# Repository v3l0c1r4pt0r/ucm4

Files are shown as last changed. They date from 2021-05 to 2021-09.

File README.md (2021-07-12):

# uCM4

Raspberry Pi Compute Module 4 micro carrier board

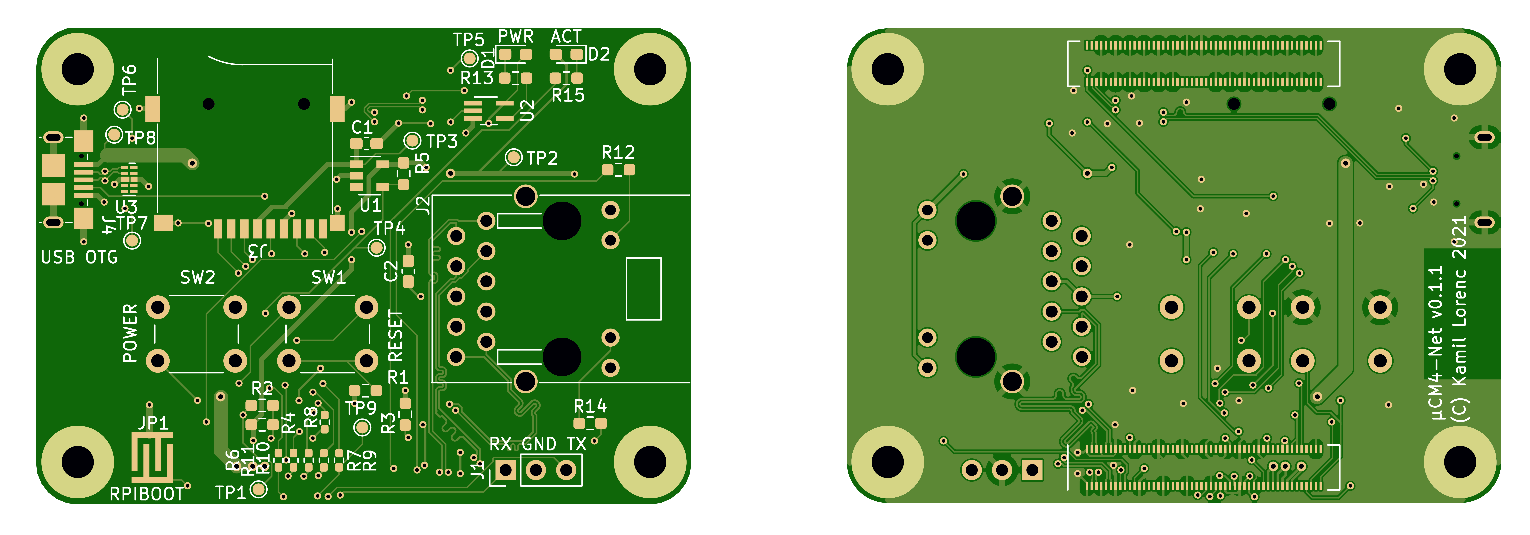
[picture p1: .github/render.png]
PCB render


# Features

* exactly same size as CM4
* support for both Lite and eMMC variants of CM4
* Gigabit Ethernet
* microSD slot (optional)
* Micro USB for power and USB 2.0 data transfer
* USB-OTG support

# Table of contents

1. [Customizations](customizations.md)
2. [Troubleshooting](troubleshooting.md)

# Project page

Complete project page with pictures, updates and so on, is available at
[Hackaday.io](https://hackaday.io/project/179793-ucm4).

# License

This work is licensed under a [Creative Commons Attribution 4.0 International License][cc-by].

You can use it for anything as long as you preserve license file and author information in source distribution and authorship information on PCB. Derived work should mention original author in same locations as this repository.

[][cc-by]

[cc-by]: http://creativecommons.org/licenses/by/4.0/
[cc-by-image]: https://i.creativecommons.org/l/by/4.0/88x31.png

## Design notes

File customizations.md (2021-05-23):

# uCM4 customizations

Following items can be changed without redesigning the board

## No microSD slot

microSD slot has been designed to be optional feature. For this purpose 0 Ohm
resistors are placed on data lines as close to Hirose connector, as was
possible. Following items should not be fitted in this case:

1. TF-015 microSD slot
2. R6-R11 0 Ohm resistors
3. RT9742CGJ5F chip marked as U1
4. R5 resistor between `SD_PWR_ON` and `SD_EN`

## Writable EEPROM

By default CM4 EEPROM has been locked, meaning it cannot be written to. This
lock can be lifted by removing R3 0 Ohm resistor.

## Power and reset buttons

These buttons can be either fitted, or not, depending on user preference.

## UART header

Same as with buttons. Can be skipped, depending on preference.

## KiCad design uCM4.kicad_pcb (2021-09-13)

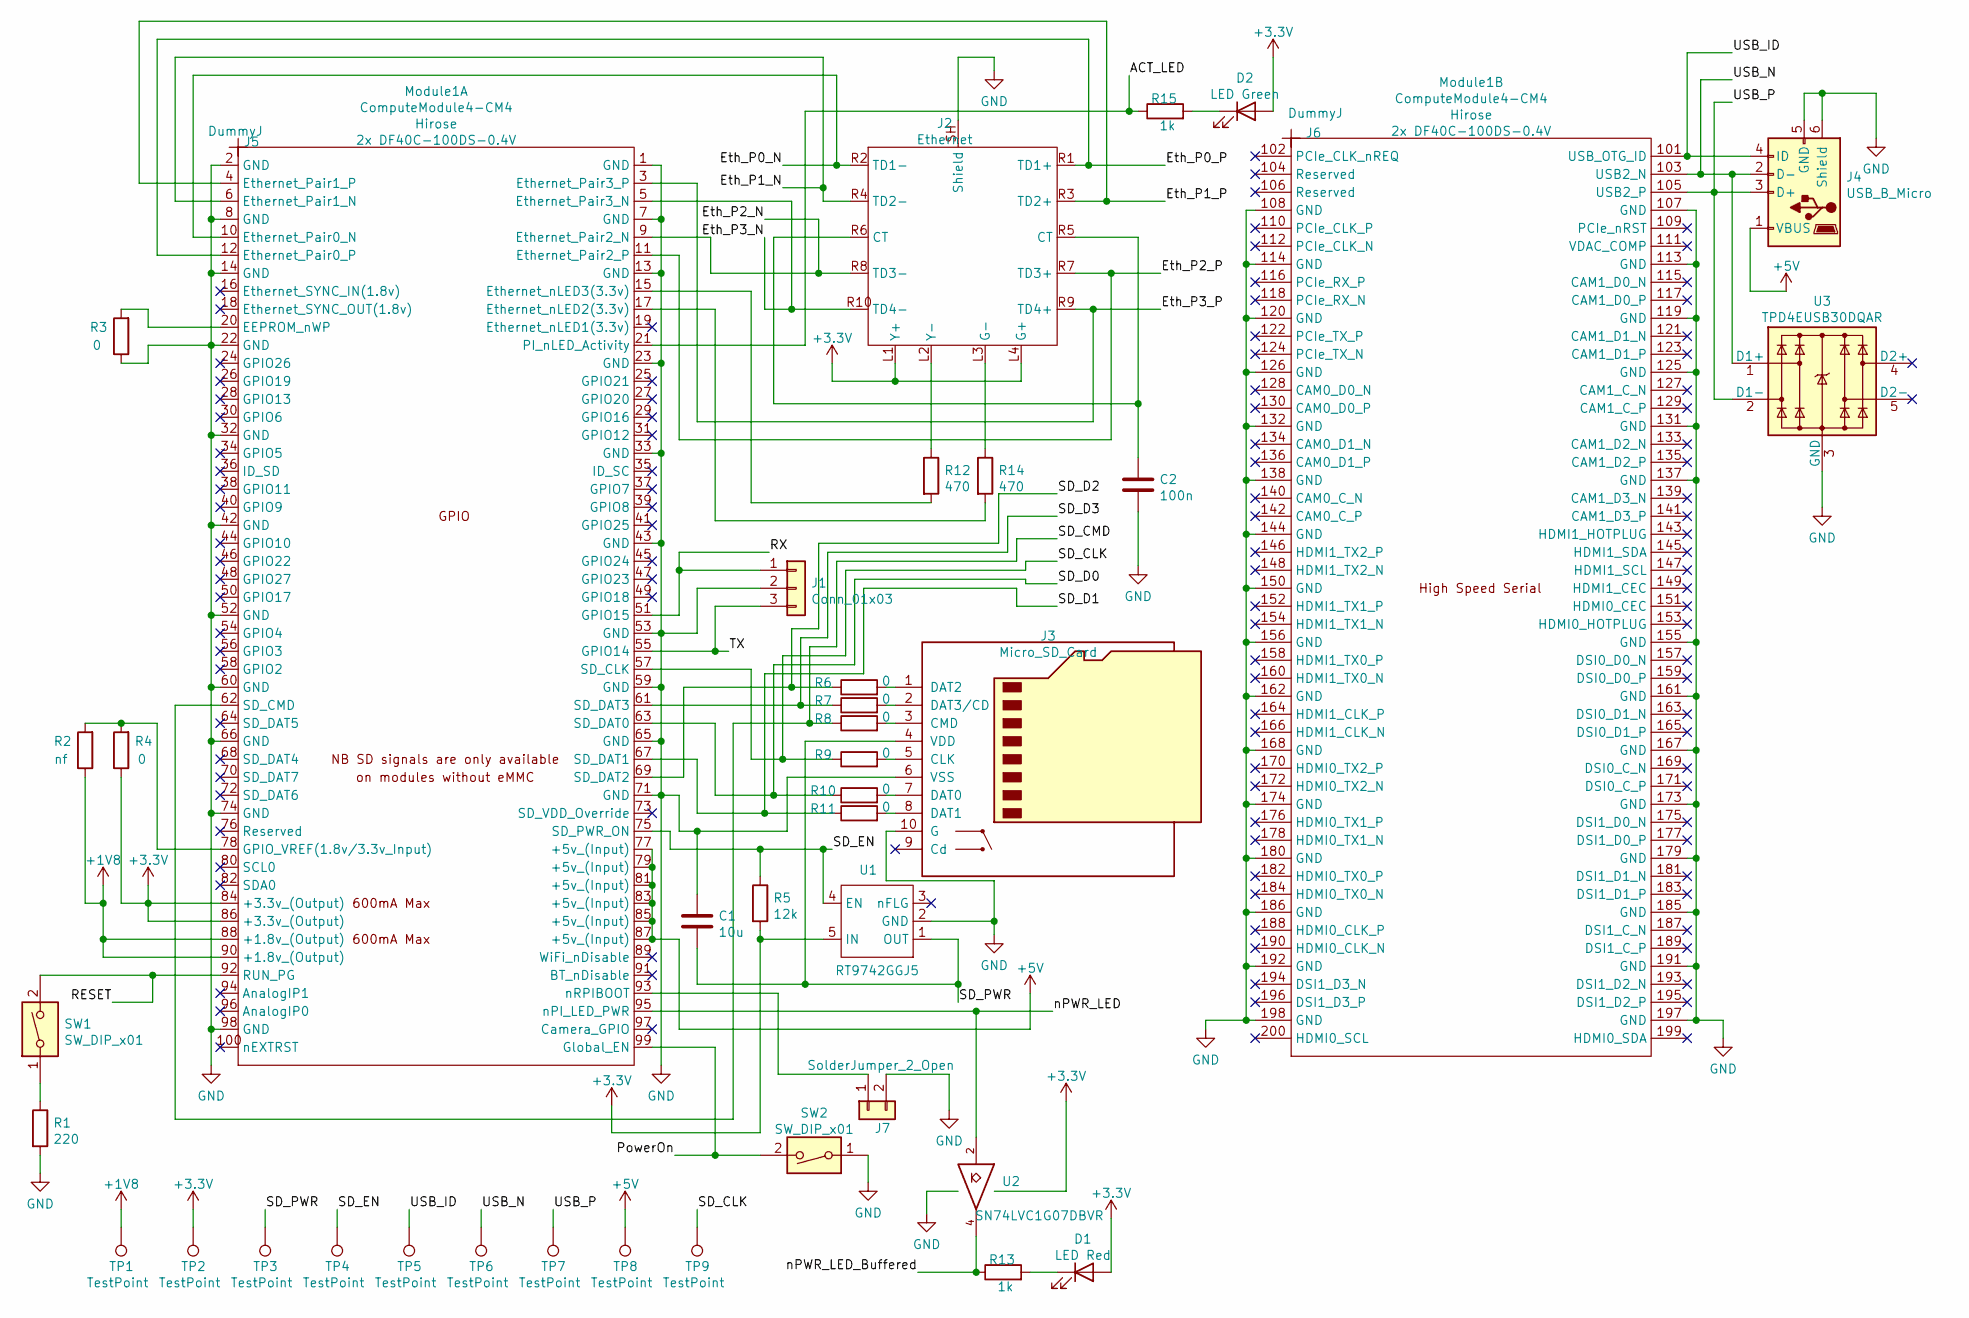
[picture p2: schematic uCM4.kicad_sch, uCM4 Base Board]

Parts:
C1: 10u; C_0603_1608Metric_Pad1.08x0.95mm_HandSolder; LCSC# C326057
C2: 100n; C_0603_1608Metric_Pad1.08x0.95mm_HandSolder; LCSC# C108079
D1: LED Red; LED_0603_1608Metric_Pad1.05x0.95mm_HandSolder; LCSC# C181863
D2: LED Green; LED_0603_1608Metric_Pad1.05x0.95mm_HandSolder; LCSC# C72043
J1: Conn_01x03; PinHeader_1x03_P2.54mm_Vertical; LCSC# C49257
J2: Ethernet; RB1-2S5BAK1A; LCSC# C363232
J3: Micro_SD_Card; TF-015; LCSC# C113206
J4: USB_B_Micro; U254-05XX-4BH81; LCSC# C2682232
J5, J6: DummyJ; LCSC# C424649
J7: SolderJumper_2_Open; PinHeader_1x02_P2.54mm_Vertical
Module1: ComputeModule4-CM4; Raspberry-Pi-4-Compute-Module; LCSC# C424649
R1: 220; R_0603_1608Metric_Pad0.98x0.95mm_HandSolder; LCSC# C22962
R2: nf; R_0603_1608Metric_Pad0.98x0.95mm_HandSolder
R3, R4: 0; R_0603_1608Metric_Pad0.98x0.95mm_HandSolder; LCSC# C21189
R5: 12k; R_0603_1608Metric_Pad0.98x0.95mm_HandSolder; LCSC# C22790
R6, R7, R8, R9, R10, R11: 0; R_0402_1005Metric_Pad0.72x0.64mm_HandSolder; LCSC# C17168
R12, R14: 470; R_0603_1608Metric_Pad0.98x0.95mm_HandSolder; LCSC# C23179
R13, R15: 1k; R_0603_1608Metric_Pad0.98x0.95mm_HandSolder; LCSC# C21190
SW1, SW2: SW_DIP_x01; PTS840_PM_SMTR_LFS; LCSC# C221911
TP1, TP2, TP3, TP4, TP5, TP6, TP7, TP8, TP9: TestPoint; TestPoint_Pad_D1.0mm
U1: RT9742GGJ5; SOT-23-5; Part Description Power Switch/Driver 1:1 N-Channel 1A TS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; LCSC# C2693603
U2: SN74LVC1G07DBVR; SOT-23-5_HandSoldering; LCSC# C7829
U3: TPD4EUSB30DQAR; USON-10_2.5x1.0mm_P0.5mm; LCSC# C90627

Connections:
+1V8: Module1.88 (+1.8v_(Output)), Module1.90 (+1.8v_(Output)), R2.1, TP1.1
+3V3: D1.2 (A), D2.2 (A), J2.L1 (Y+), J2.L4 (G+), Module1.84 (+3.3v_(Output)), Module1.86 (+3.3v_(Output)), R4.1, R5.2, TP2.1, U1.5 (IN), U2.5 (VCC)
+5V: J4.1 (VBUS), Module1.77 (+5v_(Input)), Module1.79 (+5v_(Input)), Module1.81 (+5v_(Input)), Module1.83 (+5v_(Input)), Module1.85 (+5v_(Input)), Module1.87 (+5v_(Input)), TP8.1
/ACT_LED: Module1.21 (PI_nLED_Activity), R15.1
/Eth_P0_N: J2.R2 (TD1-), Module1.10 (Ethernet_Pair0_N)
/Eth_P0_P: J2.R1 (TD1+), Module1.12 (Ethernet_Pair0_P)
/Eth_P1_N: J2.R4 (TD2-), Module1.6 (Ethernet_Pair1_N)
/Eth_P1_P: J2.R3 (TD2+), Module1.4 (Ethernet_Pair1_P)
/Eth_P2_N: J2.R8 (TD3-), Module1.9 (Ethernet_Pair2_N)
/Eth_P2_P: J2.R7 (TD3+), Module1.11 (Ethernet_Pair2_P)
/Eth_P3_N: J2.R10 (TD4-), Module1.5 (Ethernet_Pair3_N)
/Eth_P3_P: J2.R9 (TD4+), Module1.3 (Ethernet_Pair3_P)
/PowerOn: Module1.99 (Global_EN), SW2.2
/RESET: Module1.92 (RUN_PG), SW1.2
/RX: J1.1, Module1.51 (GPIO15)
/SD_CLK: Module1.57 (SD_CLK), R9.1, TP9.1
/SD_CMD: Module1.62 (SD_CMD), R8.1
/SD_D0: Module1.63 (SD_DAT0), R10.1
/SD_D1: Module1.67 (SD_DAT1), R11.1
/SD_D2: Module1.69 (SD_DAT2), R6.1
/SD_D3: Module1.61 (SD_DAT3), R7.1
/SD_EN: Module1.75 (SD_PWR_ON), R5.1, TP4.1, U1.4 (EN)
/SD_PWR: C1.2, J3.4 (VDD), TP3.1, U1.1 (OUT)
/TX: J1.3, Module1.55 (GPIO14)
/USB_ID: J4.4 (ID), Module1.101 (USB_OTG_ID), TP5.1
/USB_N: J4.2 (D-), Module1.103 (USB2_N), TP6.1, U3.1 (D1+)
/USB_P: J4.3 (D+), Module1.105 (USB2_P), TP7.1, U3.2 (D1-)
/nPWR_LED: Module1.95 (nPI_LED_PWR), U2.2
/nPWR_LED_Buffered: R13.1, U2.4
GND: C1.1, C2.2, J1.2, J2.SH (Shield), J3.6 (VSS), J3.10 (G), J4.5 (GND), J4.6 (Shield), J7.2, Module1.1 (GND), Module1.2 (GND), Module1.7 (GND), Module1.8 (GND), Module1.13 (GND), Module1.14 (GND), Module1.22 (GND), Module1.23 (GND), Module1.32 (GND), Module1.33 (GND), Module1.42 (GND), Module1.43 (GND), Module1.52 (GND), Module1.53 (GND), Module1.59 (GND), Module1.60 (GND), Module1.65 (GND), Module1.66 (GND), Module1.71 (GND), Module1.74 (GND), Module1.98 (GND), Module1.107 (GND), Module1.108 (GND), Module1.113 (GND), Module1.114 (GND), Module1.119 (GND), Module1.120 (GND), Module1.125 (GND), Module1.126 (GND), Module1.131 (GND), Module1.132 (GND), Module1.137 (GND), Module1.138 (GND), Module1.144 (GND), Module1.150 (GND), Module1.155 (GND), Module1.156 (GND), Module1.161 (GND), Module1.162 (GND), Module1.167 (GND), Module1.168 (GND), Module1.173 (GND), Module1.174 (GND), Module1.179 (GND), Module1.180 (GND), Module1.185 (GND), Module1.186 (GND), Module1.191 (GND), Module1.192 (GND), Module1.197 (GND), Module1.198 (GND), R1.2, R3.1, SW2.1, U1.2 (GND), U2.3 (GND), U3.3 (GND), U3.8 (GND)
unnamed: C2.1, J2.R5 (CT), J2.R6 (CT)
unnamed: D1.1 (K), R13.2
unnamed: D2.1 (K), R15.2
unnamed: J2.L2 (Y-), R12.1
unnamed: J2.L3 (G-), R14.1
unnamed: J3.1 (DAT2), R6.2
unnamed: J3.2 (DAT3/CD), R7.2
unnamed: J3.3 (CMD), R8.2
unnamed: J3.5 (CLK), R9.2
unnamed: J3.7 (DAT0), R10.2
unnamed: J3.8 (DAT1), R11.2
unnamed: J7.1, Module1.93 (nRPIBOOT)
unnamed: Module1.15 (Ethernet_nLED3(3.3v)), R12.2
unnamed: Module1.17 (Ethernet_nLED2(3.3v)), R14.2
unnamed: Module1.20 (EEPROM_nWP), R3.2
unnamed: Module1.78 (GPIO_VREF(1.8v/3.3v_Input)), R2.2, R4.2
unnamed: R1.1, SW1.1

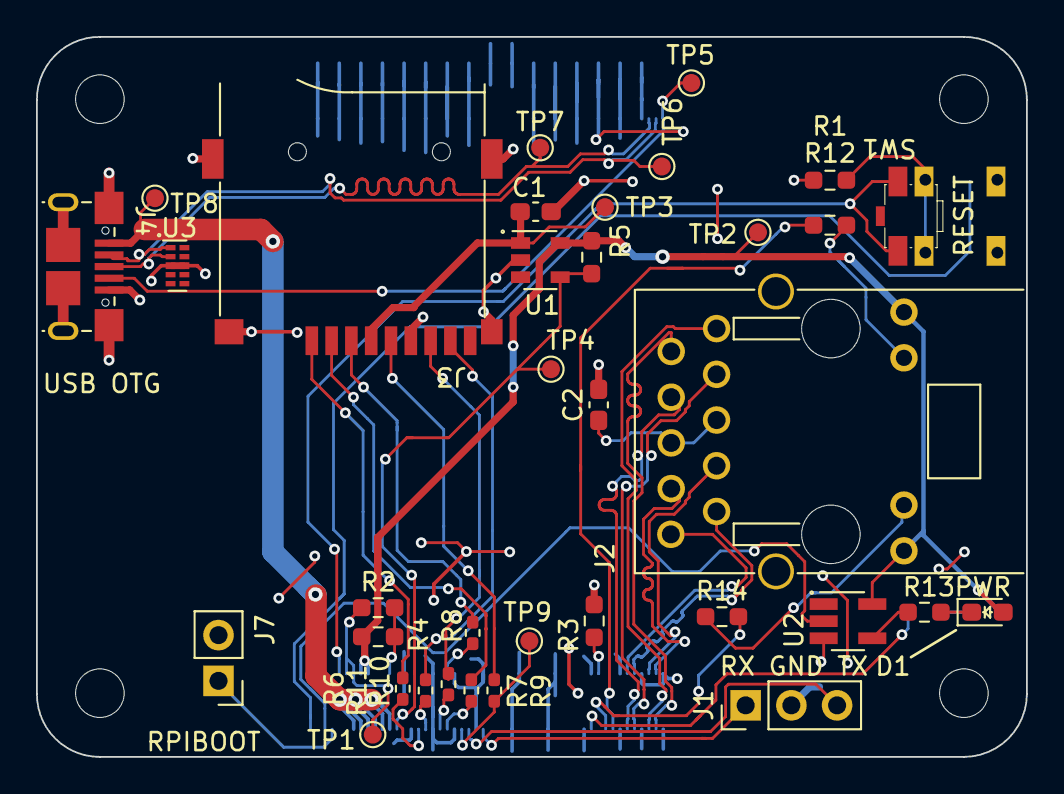
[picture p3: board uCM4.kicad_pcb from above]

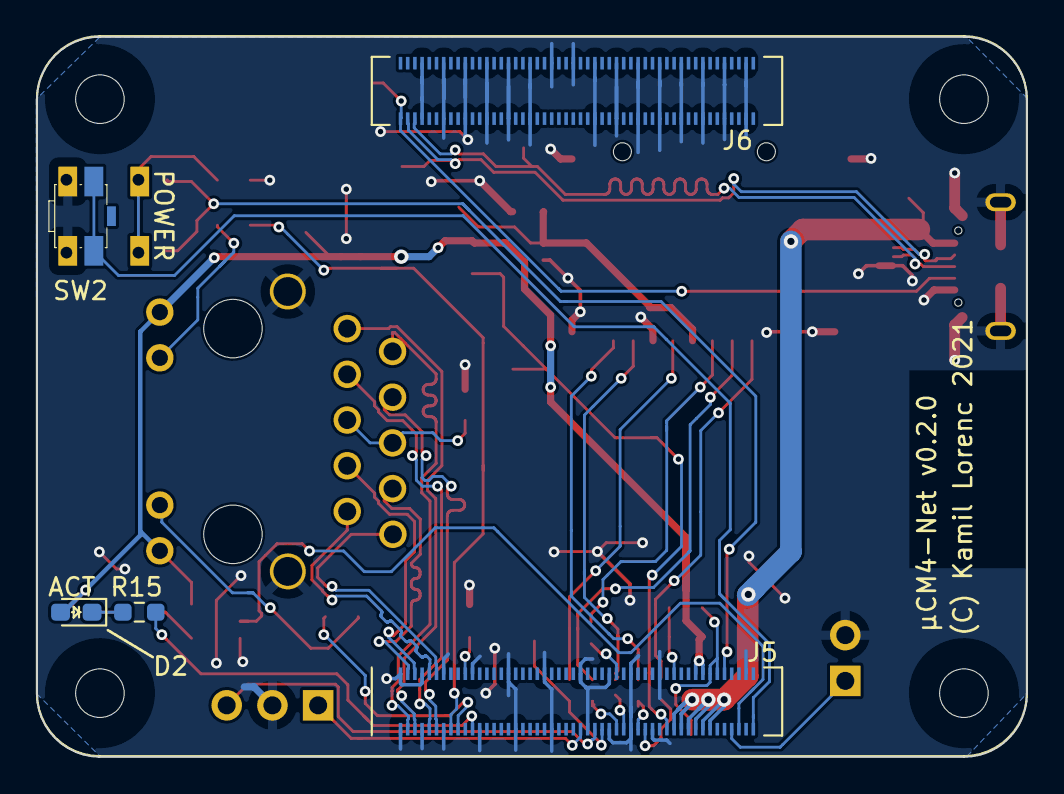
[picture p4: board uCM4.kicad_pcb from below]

Board: 2 copper layers, 55.0 x 40.0 mm, 41 parts (6 on the bottom side), 47 nets.

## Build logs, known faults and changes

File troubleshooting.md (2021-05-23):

# Troubleshooting

## Basic troubleshooting with testpoints

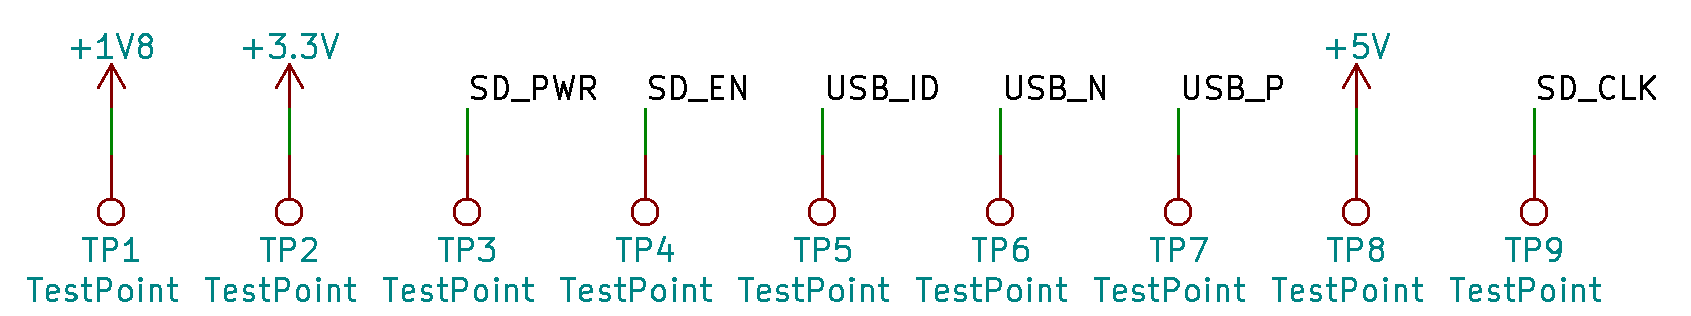
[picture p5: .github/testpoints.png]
uCM4 testpoints


For sake of troubleshooting the board, couple of testpoints were placed around the board. Above is a fragment of schematics of version 0.1.0 showing all TPs available in this version.

1. TP1 (+1V8) is rather obvious - should give 1.8 volts, once CM4 is connected and working.
2. TP2 (+3.3V) works the same way, but for 3.3 volts, supplied by CM4.
3. TP3 (SD_PWR) is the power given to SD connector with help of RT9742CGJ5F (see TP4 for input)
4. TP4 (SD_EN) is provided by CM4, once it decide to power SD card (if floating, powers card too!)
5. TP5 (USB_ID) is USB's ID pin for USB-OTG (broken on 0.1.0)
6. TP6 (USB_N) is USB D- signal (broken on 0.1.0)
7. TP7 (USB_P) is USB D+ signal (broken on 0.1.0)
8. TP8 (+5V) is 5 volts power supplied by USB connector (present always)
9. TP9 (SD_CLK) is clock of SD card connector, supplied by CM4. Transitional 400 kHz clock during early boot.

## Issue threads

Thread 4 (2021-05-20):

Ethernet connector shield hole too tight

v3l0c1r4pt0r, 2021-05-20:
This can make mounting harder and cause problems in factory.

Closed 2021-07-13.

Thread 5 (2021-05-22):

Improve RPIBOOT jumper

v3l0c1r4pt0r, 2021-05-22:
It has to be shorted for a moment while connecting to power. The idea of how it looks like right now was to short it with tweezers, screwdriver or similar tool. Reality however is that it is really hard to make short good enough, so it is treated by bootloader as low state and rpiboot is entered.

v3l0c1r4pt0r, 2021-09-13:
I did one more modification. Now it is unpopulated 2.54mm 2-pin header.

Closed 2021-09-13.

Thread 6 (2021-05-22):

Soldermask around vias

v3l0c1r4pt0r, 2021-05-22:
In version 0.1.0 soldermask clearance around vias is at JLCPCB's minimum. As a result some vias are soldermasked, some are not. Everything works, but such random pattern looks badly.

v3l0c1r4pt0r, 2021-07-13:
This problem seems to be more complex than it seems. The fact is that all vias are marked to be tented (covered with soldermask). There is nothing on mask layer. The other thing is that, when designer decides not to tent vias, then he should add clearance around via ring to +0.05mm, which is unsupported by KiCAD at the moment AFAIK.

So the only improvement at the moment is to check "Do not tent vias", when generating Gerbers. This could, but might not solve the problem. But on the other hand, sometimes tenting vias is good idea (e.g. BGA balls, maybe close to pads?).

Closed 2021-07-13.

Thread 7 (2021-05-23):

Consider using SMD tact switches for power and reset

v3l0c1r4pt0r, 2021-05-23:
6mm through hole tact switches are way too bulky for such a small board. Smallest SMD ones would be sufficient to save space.

Closed 2021-09-13.

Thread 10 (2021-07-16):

Find alternative for 74LVC1G07SE-7

v3l0c1r4pt0r, 2021-07-16:
LCSC ran out of stock. Should be fairly easy to find alternative, as this is standard part.

v3l0c1r4pt0r, 2021-08-10:
Quick search showed that SN74LVC1G07DBVR looks promising. The only problem is that it is SOT-23-5, instead of SOT-353 for current buffer chip. But this is rather simple and safe change. I have to check exact parameters to avoid surprises and do the modification.

v3l0c1r4pt0r, 2021-08-29:
I analyzed datasheets of both. They are exactly the same. The only change is package size, which was already adjusted on branch in commit 5a67ff7.

v3l0c1r4pt0r, 2021-09-13:
Fixed in 0.2.0

Closed 2021-09-13.

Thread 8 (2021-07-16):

TF-015 footprint does not match JLCPCB rendering

v3l0c1r4pt0r, 2021-07-16:
It seems that it is not properly centered and rotated. This has to be investigated further, before making any action. Especially rotation, as I based mine on original drawing.
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

For now this is reproducible only on autobom branch, but problem is deeper, as scripts on this branch simply extracts data from PCB and schematics.

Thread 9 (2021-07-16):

Ethernet connector not centered correctly

v3l0c1r4pt0r, 2021-07-16:
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
Also it might happen that rotation is wrong, but it is hard to judge from just JLCPCB rendering.

Reproducible easily on autobom branch, but exists also on master.

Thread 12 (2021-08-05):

Possible to add a superspeed USB C DRD, like dwc3

berlin4apk, 2021-08-05:
Possible to add a superspeed USB C DRD, like dwc3?

So we can power the cm4 from a USB C host, and with  gedged devices act as a offline / caching ipxe server, to install the host

v3l0c1r4pt0r, 2021-08-13:
I'm not sure if I understood you correctly. DRD is equivalent of USB-OTG that was introduced in USB 3.0. SoC on Raspberry Pi does not support USB 3.0 and never did - on Pi 4 it is separate chip that does that. But if what you want is USB gadget, then probably it is still possible. With my board I used the same USB connector that delivers power to communicate with rpiboot bootloader in slave mode from RPi perspective. The other way should also be possible with OTG.

Closed 2021-08-29.

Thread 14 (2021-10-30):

Question: Would you be willing to possibly add GPIO16 and GPIO17 to be able to use a hardware flow Serial console ?

markbirss, 2021-10-30:
Hi

Would you possibly be willing to help add GPIO16 and GPIO17 on your design to allow hardware flow control serial console ?

I have below a prototype build of a serial console to e-paper project which could be even better with a ucm4 board

Terminal using
https://github.com/vroland/epdiy

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

v3l0c1r4pt0r, 2021-11-01:
Is there any difference between pair that you mentioned and GPIO14+GPIO15? As far as I can see both can be either UART0 or UART1, so seems like there is no difference. If so, 14 and 15 is already broken out as debug port. Otherwise, existing TX and RX could be rather simply exchanged to other GPIO pins. In my opinion this is something that you could easily do yourself.

Would be a different topic if you would like to use off-the-shelf uCM4, if it becomes reality in future. In such case would be nice if you could explain benefits of this modifications, because main idea of having UART broken out was to use it for debugging and for that current implementation seems to be good enough. Or am I wrong?

markbirss, 2021-11-01:
@v3l0c1r4pt0r

Ok, the already exposed pair is good for a standard serial console connection without hardware flow control
That you generally use to for debugging as you pointed out

The additional 2 GPIO's are to enable RTS and CTS .
Hardware Flow Control requires all 4 GPIO's ie 14,15,16,17 -  RX,TX,CTS,RTS

so swapping the existing GPIO's will not help as i need 4 in total

Hardware flow adds the ability for the receiver and the transmitter to alert each other of their state.

If your serial port speed is too high for the receiver a normal serial connection will discard characters.

With hardware flow control the serial terminal screen will not drop characters like what a normal non hardware flow control serial connection will do.

Refer to the links below on more information about enabling Hardware Flow Control on the Raspberry Pi

https://github.com/mholling/rpirtscts
http://www.deater.net/weave/vmwprod/hardware/pi-rts/

v3l0c1r4pt0r, 2021-11-01:
Ah, ok, I just checked that these GPIOs are for UART 0 or 1, but did not check the signal :)

All is clear now.

markbirss, 2021-11-01:
Cool.

I also contracted Ivan Kulenshov about his MinCab (minimal Carrier Board),
but he has not yet released it
https://www.tomshardware.com/news/raspberry-pi-compute-module-4-mincab

It also an option since he exposes enough GPIO's todo hardware flow control
via a GPIO remap.

Hope you will think about adding more GPIO's

On Mon, Nov 1, 2021 at 9:12 PM Kamil Lorenc ***@***.***>
wrote:

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

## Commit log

2021-03-20 Start development
    Add library from CM4IO, place CM4 and set edge cuts. Ignore unneeded
    files.
    [uCM4.kicad_pcb, uCM4.kicad_sch]
2021-03-21 Add schematics
    Implement most of the schematics part of the project. What is left are
    less important details, like power button and LEDs. All such cases, no
    matter the reason, are marked with TODO.
    [uCM4.kicad_pcb, uCM4.kicad_sch]
2021-03-27 Implement missing parts of schematics
    Add LEDs, ESD protection on USB connector and mark some pins as unused.
    What is left for considerations is implementing RTC. Maybe Ethernet has
    to be converted to bus, as wires within a pair has to be same length.
    [uCM4.kicad_pcb, uCM4.kicad_sch]
2021-03-27 Populate PCB
    Almost all footprints ready. Missing is, most importantly, MicroUSB
    connector.
    [uCM4.kicad_pcb, uCM4.kicad_sch]
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2021-03-28 Add jumper and start routing
    Fill missing footprint assignment, most importantly, SMD jumper to
    switch to RPIBOOT temporarily. This allows to flash eMMC, if present,
    but still boot from default memory.
    [uCM4.kicad_pcb, uCM4.kicad_sch]
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2021-03-28 Attempt to fix shield of Eth
    Just a rename from Shield to SH. Seems to be failed. But, who knows.
    [uCM4.kicad_pcb, uCM4.kicad_sch]
2021-03-28 Route confident parts of PCB
    Around half of board can already be fully finished. Missing is part
    around uSD and uUSB connectors. This also makes position of tact
    switches a bit uncertain. But the rest is for sure in the right place.
    So, let's route it.
    [uCM4.kicad_pcb]
2021-03-28 Connect power of 74* buffer
    It was missing till now. Also update PCB to reflect changes.
    [uCM4.kicad_pcb, uCM4.kicad_sch]
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2021-03-29 Change TPD* vendor and package name
    Under the hood it is the same (swappable). But to be precise, let's have
    it as vendor specifies.
    [uCM4.kicad_pcb, uCM4.kicad_sch]
2021-04-03 Add new Ethernet connector
    Will eventually replace old one, as this one is available, while old
    would have to be backordered.
    [uCM4.kicad_sch]
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2021-04-03 Fix electrical connections of Eth
    Old Ethernet connector had different pin meaning, despite almost same
    footprint. Update schematics to match new connector.
    [uCM4.kicad_pcb, uCM4.kicad_sch]
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2021-04-03 Route first pair and adjust length
    Has to be done in two steps:
    1. Draw differential pair.
    2. Adjust length of differential pair tracks.
    3. Repeat (2) until net inspector shows they are even.
    [uCM4.kicad_pcb]
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2021-04-03 Start routing power buses
    Most likely not the target way to do that, but just to indicate the
    problem.
    [uCM4.kicad_pcb]
2021-04-03 Make main power line
    Base on calculator calculations. It should stand 2A current. However the
    line near connector can have only 1.2 A.
    [uCM4.kicad_pcb]
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2021-04-04 Connect shield on Micro USB connector
    This was the last error when updating PCB from schematics.
    [uCM4.kicad_pcb]
2021-04-04 Set rules from JLCPCB
    Makes number of errors lower than for defaults, but introduces errors on
    via sizes. This means some rerouting will be required.
    [uCM4.kicad_pcb]
2021-04-04 Eliminate problems on Ethernet connector
    [uCM4.kicad_pcb]
2021-04-04 Fix errors on Micro USB connector
    Is now all fine.
    [uCM4.kicad_pcb]
2021-04-04 Fix main power rail
    From MicroUSB up to Hirose all is fine on 5V rail.
    [uCM4.kicad_pcb]
2021-04-04 Reroute USB pair
    Should now be DRC error-free.
    [uCM4.kicad_pcb]
2021-04-04 Fix edge cuts
    Now complies with DRC.
    [uCM4.kicad_pcb]
2021-04-04 Improve compliance with DRC
    Most of the issues are solved. What is left is Ethernet differential
    pairs, which is the hardest part. Also there is something on Micro SD
    connector, but this is unfinished anyway, so don't care for now.
    [uCM4.kicad_pcb]
2021-04-04 Cleanup Eth connector
    Remove all measuring lines on User.Drawing layer. This makes footprint
    production-ready.
    [uCM4.kicad_pcb]
2021-04-04 Fix Micro SD connector
    Most likely is generally fine now. Some rerouting was required due to
    the change in footprint layout.
    [uCM4.kicad_pcb, uCM4.kicad_sch]
2021-04-04 Fix error with Micro SD silkscreen
    [uCM4.kicad_pcb]
2021-04-04 Fix Micro USB connector
    It seems that at least 3 versions of datasheets exists. One of them
    seems to have completely broken some of the dimensions. This led to
    misplacement on PCB and conflict with Hirose connector. The other
    datasheets differ in electrical characteristics. So in case of
    mechanical dimensions, we can try believing them. Also photo shared by
    LCSC confirms the theory that they are right. So, for now, we assume
    that official site shares the correct datasheets. Chinese is more
    trustworthy in terms of minor characteristics.
    [uCM4.kicad_pcb]
2021-04-04 Remove all routining beside main power rail
    5V rail should be fine, as it keeps distance from faulty sections and
    chances are Micro USB (and Hirose) will stay at their places.
    [uCM4.kicad_pcb]
2021-04-04 Fix conflict of Micro SD and Hirose
    Swap Micro SD with LEDs, move Ethernet downwards and fix positions of
    most of minor components.
    [uCM4.kicad_pcb]
2021-04-04 Remove notes from Eth connector
    Remove all lines on User.Drawings layer that were used for designing and
    checking the connector footprint.
    [uCM4.kicad_pcb]
2021-04-04 Draw stands on Micro SD connector
    It conflicts with mounting hole and this is the only problem on the
    whole board at the moment. There are two ways to solve this, as it is
    the only place where it (almost) fits:
    1. Make ground plane of Micro SD a bit smaller - in the worst case will
    not mount connector to PCB
    2. Remove mounting hole of module - will make two boards a little bit
    less stable together
    As of now it is undecided what option to take.
    [uCM4.kicad_pcb]
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2021-04-07 Reroute Ethernet and suroundings
    All traces intersecting with Ethernet had to be removed to make
    rerouting easier. Then Ethernet pairs were routed again. No length
    adjustments has been done yet.
    [uCM4.kicad_pcb]
2021-04-07 Adjust Ethernet pair and in-pair lengths
    Almost complete - shortest path has in-pair difference of 0.8 mm. Let's
    try again.
    [uCM4.kicad_pcb]
2021-04-07 Fix zeroth Ethernet pair
    Now it is in tolerance. Now it is a question, if another attempt for
    pair-to-pair difference reduction makes any sense.
    [uCM4.kicad_pcb]
2021-04-10 Readjust Ethernet traces
    Now they are almost perfect. Highest pair-to-pair error is ~1.5mm, while
    highest in-pair error is 0.04mm.
    [uCM4.kicad_pcb]
2021-04-10 Recreate all deleted traces
    During Ethernet rerouting, some other traces were deleted. Create them
    from scratch. Now board seem to be lacking only ground plane and its
    connections.
    [uCM4.kicad_pcb]
2021-04-10 Create ground plane and connect pins
    Connect almost all ground pads/pins to newly created ground plane on
    green layer (B). There are 2 issues with Hirose connector grounds near
    SD connection and Ethernet.
    [uCM4.kicad_pcb]
2021-04-10 Reduce error count
    Some unconnected pads were possible to connect.
    [uCM4.kicad_pcb]
2021-04-10 Fix some grounds
    Last one left. Also there is TODO, but this is I2C that most likely
    won't be connected.
    [uCM4.kicad_pcb]
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2021-04-11 Add courtyard around Eth commector
    Set to 1.25mm - is maximum courtyard specified by JLCPCB. Will see if
    this would be final.
    [uCM4.kicad_pcb]
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2021-04-13 Fix Micro USB courtyard and fab layer
    Updates based on physical view of the connector.
    [uCM4.kicad_pcb]
2021-04-13 Clear drawings on Micro SD
    Remove all dimension lines, used for drawing the footprint. They are not
    needed anymore. Footprint is finished.
    [uCM4.kicad_pcb]
2021-04-13 Fix various DRC errors
    Setting courtyards revealed some minor problems.
    [uCM4.kicad_pcb]
2021-04-13 Fix overlapping pad and pin on uUSB
    Datasheet suggested alignment pin to be overlapped with ground pad.
    However KiCAD complains. As can be seen on physical element, pad can
    safely be a lot smaller on the pin side. So let's shrink it a bit to fix
    the issue.
    [uCM4.kicad_pcb]
2021-04-13 Fix Ethernet shield
    Symbol had shield pin unnamed, therefore there was no connection between
    it and PCB. Naming, updating symbol and footprint, the redoing DRC fixed
    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
    [uCM4.kicad_pcb, uCM4.kicad_sch]
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2021-04-16 Add new Micro USB footprint
    It was overlooked that element was swapped in BOM from *4BH83 to *4BH81.
    As a result former was used till now. The only difference, fortunately
    is throught hole mounting point, so only minor fix in routing was
    needed.
    Still there is weird issue with one ground pad, that does not want to
    update itself.
    [uCM4.kicad_pcb, uCM4.kicad_sch]
2021-04-16 Fix pad-NPTH conflict on Micro USB connector
    [uCM4.kicad_pcb]
2021-04-16 Micro USB: Fix silkscreen footprint
    [uCM4.kicad_pcb]
2021-04-16 Increase margins on Ethernet connector
    Just in case, make silkscreen margin a bit larger.
    [uCM4.kicad_pcb]
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2021-04-16 Fix Micro SD silkscreen
    [uCM4.kicad_pcb]
2021-04-16 Remove CM4 outline from silkscreen
    It was at the same location as edge cuts, so would be broken.
    [uCM4.kicad_pcb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]
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2021-04-17 Add various test points
    Might be useful in case of problems. Not connected on PCB, yet.
    [uCM4.kicad_pcb, uCM4.kicad_sch]
2021-04-17 Fix hole-silkscreen conflict
    [uCM4.kicad_pcb]
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2021-05-20 Fix width of main power rail
    By mistake it was normal trace width near Hirose connector, while it
    should be 1.2 mm. To fix that with as little change as possible, set it
    to 2/3 of its required width after first Hirose pin trace is branched,
    then to 1/3 after second branch. This should not harm as whatever
    current it needs to carry will be split between 6 traces near the
    This fixes #2.
    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
    [uCM4.kicad_pcb]
2021-05-20 Change location of TP5
    I thought it was the reason for no via going to it. The real reason
    turned out to be forgetting to regenerate drill files. Nevertheless it
    does not harm, so let's leave it as it is.
    Done as a result of #1.
    [uCM4.kicad_pcb]
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2021-07-13 Do not tent vias
    For development is perfectly fine. Might cause issue, when via is close
    to a pad. This is the only improvement that can be done in context of
    issue #6.
    [uCM4.kicad_pcb]
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2021-07-13 Switch Ethernet connector to randoms
    This fixes issue #4. In KiCAD_Randoms it is already fixed for some time.
    [uCM4.kicad_pcb, uCM4.kicad_sch]
2021-07-13 Remove unused Connector_RJ library
    Most likely was attempted to use it for Ethernet connector, but never
    succeeded in this. And contained absolute path to directory, which no
    other user beside me has.
    [uCM4.kicad_pcb]
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2021-07-13 Move J2 label back to its original position
    This is a bug caused by changing Ethernet footprint to different
    library.
    [uCM4.kicad_pcb]
2021-07-13 Add U1-U3 to BOM and fix CPL
    Rotation was not set, thus invalid in CPL file.
    Also add LCSC part numbers to BOM, so all three SMD IC can be optionally
    placed by JLCPCB SMT assembly service. All ICs are on extended list, so
    most likely are uneconomical to place, unless connectors are placed too.
    [bom.csv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]
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2021-08-13 Make preparations for required changes in 0.2.0
    Following has been performed and could not be made separately:
    - move LEDs to smaller space next to Ethernet
    - move buttons to bigger space next to Ethernet
    - two changes above makes together handy interface for whole board,
    where almost everything needed is on one side
    - move all parts belonging to LEDs and buttons near their new locations
    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
    [uCM4.kicad_pcb, uCM4.kicad_sch]
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2021-08-13 Power buttons - issue #7
    [uCM4.kicad_pcb, uCM4.kicad_sch]
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2021-08-25 Add LCSC# to symbols
    Still connectors are missing them, but allows generating BOM as good as
    present in repo - manual one.
    [uCM4.kicad_sch]
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2021-08-25 Update part names and add LCSC#
    For 74LVC1G07 buffer and power+reset buttons.
    [uCM4.kicad_sch]
2021-08-25 Update PCB after schematics changes
    Most significantly LCSC# and some part names. Nothing important from PCB
    perspective, despite amount of changes.
    [uCM4.kicad_pcb]
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2021-08-25 Update kicad-randoms subrepo
    Now PTS840 should be fixed. Till this commit it might cause problems,
    when opening PCB.
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2021-08-26 Fix most obvious 6mil clearance errors
    Beside signal buses - USB and Ethernets, almost everything is fine now.
    [uCM4.kicad_pcb]
2021-08-26 Add missing track and via sizes
2021-08-26 Remove TODO
    5V is already here. I don't know why I wrote that :)
    [uCM4.kicad_pcb]
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2021-08-27 Fix minor clearance errors
    Now most of the board has clearance of >6 mils (1.6 mm). This makes
    manufacturing in most of the factories way cheaper. What is left is USB
    differential pair and two small issues near the connector.
    [uCM4.kicad_pcb]
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2021-08-29 Adjust TVS diode footprint to fix DRC errors
    Pads must be slightly smaller to fit into 6 mils limit (~0.02 mm
    smaller). Should not harm.
    [uCM4.kicad_pcb]
2021-08-29 Fix diff pair gap for USB
    Was still set to 0.13 mm, which caused DRC errors on routing and made
    successful routing impossible.
    [uCM4.kicad_pcb]
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2021-08-29 Reconnect SD's D2 and GDN on pin 71
    Lack of connection from pin 71 on low speed connector was last problem
    that DRC reported. By the way via for D2 has to be moved to allow
    track from GND go its way. At this point DRC is green.
    [uCM4.kicad_pcb]
2021-08-29 Reroute connection to TP1 a bit
    At a cost of one additional via makes 1V8 track shorter and TP1 closer
    to Hirose connector.
    [uCM4.kicad_pcb]
2021-08-29 Swap sides for power and reset button
    It is more convenient to have reset on top, as it is not at the edge of
    board. Also it decreases a risk of damage to CM4, as it may happen
    someone will try to reset with conductive, metal thing and touch
    something on CM4. Having power button on bottom (CM4) side does not pose
    that risk as it is exactly at the edge.
    [uCM4.kicad_pcb]
2021-08-29 Change jumper to standard size and shape
    This closes issue #5.
    [uCM4.kicad_pcb]
2021-08-29 Tent vias again
    Not tenting them makes assembly harder, when done manually. When machine
    does that, it may simply fail by making short or something.
    [uCM4.kicad_pcb]
2021-09-04 Commit missed jumper on schematics
    [uCM4.kicad_sch]
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2021-09-04 Add dummy symbol and footprint for Hirose
    CM4 is two-unit symbol with one footprint, designated Module1, which is
    useless for fabrication. Add two dummy symbols marking both Hirose
    connectors as ordinary J? parts. This allows them to appear on
    silkscreen automagically and also be in BOM as proper entries. Only
    unlinked to real pads, but who cares.
    [uCM4.kicad_pcb, uCM4.kicad_sch]
2021-09-05 Make a lot of small changes for RFM
    Release for Manufacturing require some otherwise not important details
    to be correctly set. These include manufacturer part numbers for BOM,
    origin point being set, designators on fab layer for PDF generation.
    When assembly was done on JLCPCB, only custom pick&place file and BOM,
    almost auto-generated was important. For more traditional factory, more
    work needs to be done. This commit fixes a lot of such small things.
    [uCM4.kicad_pcb, uCM4.kicad_sch]
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2021-09-05 Remove BOM and P&P files
    They are not up to date anymore.
    [bom.csv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]
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2021-09-06 Change track widths to >6mil
    Most of the tracks could be changed to 0.16 mm straight away. Some
    generated clearance violation. But generally, besides Ethernet, which is
    always a problem, should not be so hard to fix.
    [uCM4.kicad_pcb]
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2021-09-07 Fix TVS diode footprint to fit into clearance
    Clearance should be at least 6mils (~1.6 mm). This should not cause
    problems with soldering (hopefully).
    [uCM4.kicad_pcb]
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2021-09-07 Make ground plane on USB connector smaller
    Now it fits into >6mils constraint for clearance.
    [uCM4.kicad_pcb]
2021-09-07 Modify keepout of Ethernet and connect tracks
    Keepout area does not have to forbid tracks from appearing under it.
    Remove this constraint and connect last missing track. Now all errors,
    beside Ethernet are fixed.
    [uCM4.kicad_pcb]
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2021-09-07 Redo Ethernet tracks
    Now DRC passes on 0,16 mm setting. Ethernet length matching not done
    yet.
    [uCM4.kicad_pcb]
2021-09-07 Match Ethernet track lengths within pairs
    All pairs are almost perfectly same length now.
    [uCM4.kicad_pcb]
2021-09-07 Reset origin point
    Let it be 2mm to the left and down from virtual left-bottom corner.
    [uCM4.kicad_pcb]
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2021-09-08 Add courtyard to dummy Hirose J
    Dummy Hirose entities must have proper center point, so they can be
    mounted properly at the factory site. Add courtyard based on the
    silkscreen layer for real connectors. Do it on user drawings, so nobody
    will use this footprint further.
    [uCM4.kicad_pcb]
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2021-09-08 Couple fixes on fab layer
    Nothing really important. Might be useful for boardview.
    [uCM4.kicad_pcb]
2021-09-09 Change RPIBOOT jumper into 2-pin header
    This would make it easier to short it. Even with tweezers.
    [uCM4.kicad_sch]
2021-09-09 Change footprint for rpiboot
    Now it is standard 2.54 2-pin header. Will not be populated in fab by
    default!
    [uCM4.kicad_pcb, uCM4.kicad_sch]
2021-09-11 Change footprint for TVS diode
    It was set to the package that was most similar to the naming of
    Diodes-made diode. Now we use TI part and also for safety and
    convenience, replace it to USON-10. This one is 6mil-compatible
    out-of-the-box.
    [uCM4.kicad_pcb, uCM4.kicad_sch]
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2021-09-12 Various different fixes on PCB
    There was incorrect footprint committed for J3 and J4. Now I don't know
    what else changed with this commit.
    [uCM4.kicad_pcb]
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2021-09-12 Fix DRC on U3 designator
    [uCM4.kicad_pcb]
2021-09-12 Fix ground size on J4
    [uCM4.kicad_pcb]
2021-09-12 Fix DRC on TVS diode
    [uCM4.kicad_pcb]
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
